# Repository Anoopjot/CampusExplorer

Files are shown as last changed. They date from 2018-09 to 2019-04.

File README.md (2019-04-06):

# Creating i2c Device(using ATtiny85, TMP36 and Arduino)

It involves various steps and the steps goes as follows:

Step 1. [Programming the Arduino(so that it can program ATtiny85)](https://github.com/HumberCampusExplorer/CampusExplorer#1-programming-the-arduino-to-program-the-attiny85)

Step 2. [Programming the ATtiny85](https://github.com/HumberCampusExplorer/CampusExplorer#2-programming-the-attiny85)

Step 3. [Wiring the circuit(Wiring Arduino + ATtiny85 + TMP36)](https://github.com/HumberCampusExplorer/CampusExplorer#3-wiring-the-circuit)

Step 4. [Programming the Arduino-To act as a master device](https://github.com/HumberCampusExplorer/CampusExplorer#4-programming-the-Arduino-to-act-as-a-master-device)

Step 5. [Power up the circuit](https://github.com/HumberCampusExplorer/CampusExplorer#5-power-up-the-circuit)

Step 6. [Testing](https://github.com/HumberCampusExplorer/CampusExplorer#6-testing)

Step Final. [Raspberry Pi](https://github.com/HumberCampusExplorer/CampusExplorer#creating-i2c-device(using-ATtiny85-TMP36-and-Arduino))

## Steps to program ATTiny85
[Follow this link](https://quadmeup.com/attiny85-light-sensor-i2c-slave-device/)

## 1 Programming the Arduino to program the ATtiny85
1. Stuff needed and used:-
- Arduino
- Breadboard
- ATtiny85 
- 220ohm 1/4 watt resistor
- LED
- hookup wires

2. Wire the circuit 

Connect the Arduino to the ATtiny as follows:

- Arduino +5V      --->  ATtiny Pin 8,

- Arduino Ground   --->  ATtiny Pin 4,

- Arduino Pin 10   --->  ATtiny Pin 1,

- Arduino Pin 11   --->  ATtiny Pin 5,

- Arduino Pin 12   --->  ATtiny Pin 6,

- Arduino Pin 13   --->  ATtiny Pin 7.

attiny85breadboardattiny85
arduino attiny85

3. Program the Arduino, so that it can program the microcontroller(ATtiny85), using "Arduino" software. To do that 3 steps need to be follow:

-> Select the "ArduinoISP" sketch from the "Examples" menu.

-> Upload the sketch to Arduino.

-> Check and make sure, from tools, the board selected is "Arduino/Genuino Uno",Port selected is same as the port on which the arduino is connected with the computer and select the programmer "AVR ISP", otherwise it will give the error related to serial.

-> And Finally, upload it.

-> Arduino is now configured as a serial programmer that can program other chips.

4. Add the Attiny85 core files by adding the following file/Folder url to arduino preferences:

[ATtiny_85](https://raw.githubusercontent.com/damellis/attiny/ide-1.6.x-boards-manager/package_damellis_attiny_index.json)

and going to board the manager and adding the board ATtiny85.

Unzip the .zip folder and save it in Arduino>libraries>

5. Program the ATtiny85

Select from the top menu:

Tools --> Board --> ATtiny85 (w/ Arduino as ISP)

Change the Programmer to "Arduino as ISP".

Then open the basic blink example and change the pin number from 13 to 4 and upload it.

6. Tested the circuit.

blinkled


and it shows that now arduino can program the ATtiny 85.

## 2 Programming the ATtiny85 

Now, we will be programming the ATtiny85 to act as slave,so that it can retrieve data(Analog value) from sensor(TMP36) and convert it to digital and send it to Raspberry pi, when requested.

First i am testing my circuit and program on Arduino(instead of Raspberry pi directly), to make troubleshooting easier.
For this purpose we need library, TinywireS libirary  from link
[TinyWireS_library](https://github.com/nadavmatalon/TinyWireS)

For that i uploaded this code on ATtiny85
```
/*
 * Set I2C Slave address. You can have multiple sensors with different addresses
 */
#define I2C_SLAVE_ADDRESS 0x30

/*
 * How often measurement should be executed
 * One tick is more less 0.5s, so 1 minute is 120 ticks
 * This executes measurements every 2 minutes, so 120s, 120000 ms
 */
#define MAX_TICK 50
#define STATUS_PIN_1 4
#define ADC_PIN A3
#define LPF_FACTOR 0.5

#include <TinyWireS.h>
#include <avr/sleep.h>
#include <avr/wdt.h>

#ifndef TWI_RX_BUFFER_SIZE
#define TWI_RX_BUFFER_SIZE ( 16 )
#endif

volatile uint8_t i2c_regs[] =
{
    0, //older 8
    0 //younger 8
};

volatile byte reg_position = 0;
const byte reg_size = sizeof(i2c_regs);
volatile unsigned int lightMeter;

/**
 * This function is executed when there is a request to read sensor
 * To get data, 2 reads of 8 bits are required
 * First requests send 8 older bits of 16bit unsigned int
 * Second request send 8 lower bytes
 * Measurement is executed when request for first batch of data is requested
 */
void requestEvent()
{  
  TinyWireS.write(i2c_regs[reg_position]);

  reg_position++;
  if (reg_position >= reg_size)
  {
      reg_position = 0;
      digitalWrite(STATUS_PIN_1, LOW);
  }
}

void setup() {
  /*
   * Setup I2C
   */
  TinyWireS.begin(I2C_SLAVE_ADDRESS);
  TinyWireS.onRequest(requestEvent);

  /*
   * Set pins
   */
  pinMode(STATUS_PIN_1, OUTPUT);
  pinMode(ADC_PIN, INPUT);
}

unsigned int tick = 0;
unsigned long lastReadout = 0;

int smooth( int data, float filterVal, float smoothedVal){
return(data);
}

void loop() {

  unsigned long currentMillis = millis();
  /*
   * On tick value 0, do measurements
   */
  if (abs(currentMillis - lastReadout) > MAX_TICK) {
   int raw_value = analogRead(ADC_PIN);
   
    lightMeter = smooth(raw_value, LPF_FACTOR, lightMeter);
    
    i2c_regs[0] = (lightMeter >> 8) & 0xFF;     // shifting the 8 bits
    i2c_regs[1] = lightMeter & 0xFF;            
    
    digitalWrite(STATUS_PIN_1, HIGH);
    lastReadout = currentMillis;
  }
}
```
* check for Board choose "ATtiny85" and programmer as "Arduino as ISP".
And upload the code.

## 3 Wiring the circuit
(Wiring Arduino + ATtiny85 + TMP36)

ATtiny 85 & TMP36
- Pin2 (ATtiny85) -> centre pin(tmp36)
- Pin 1(TMP36) -> 5v
- Pin3 (TMP36) -> Ground

To check pins of TMP36

tmp36pinout

Arduino & ATtiny85
- Pin4(ATtiny85) - Ground
- Pin8(ATtiny85) - Vcc(5v)
- Pin5(ATtiny85) - SDA (Arduino)
- Pin7(ATtiny85) -SCL (Arduino)
We need to insert pull-up resistor (nearly 4.7k ohm ) between pin 5 (ATtiny85) and Vcc && between pin 7 (ATtiny85) and Vcc.

Then attach the auduino with USB cable type A/B with computer to power up Arduino.

pcbwithtmp36arduinobbwithtmp36arduino
arduinoattiny85tmp36

# 4 Programming the Arduino to act as a master device

For this i just uploaded a sketch to arduino.

For that i changed the options from ARDUINO software=> 
- Tools-> Board:"Arduino/Genuino uno" and 
- Tools-> Programmer:"AVR ISP"

AND then uploaded the "sketch"

```
#include <Wire.h>

int i = 0;
unsigned int readout = 0;
byte FirstByte =0;
byte SecondByte =0;
 
void setup() {
  Serial.begin(9600);  // start serial for output
  Serial.println("starting");
  Wire.begin();        // join i2c bus (address optional for master)
}

void loop() {
  Wire.requestFrom(0x30, 1);    // request 1 bytes from slave device #0x13
 while(Wire.available()){
 FirstByte = Wire.read();
}

Wire.requestFrom(0x30, 1);    // request 1 bytes from slave device #0x13
 while(Wire.available()){
 SecondByte = Wire.read();
}
 readout = FirstByte << 8|SecondByte;       // putting them together
 Serial.println(readout);
 delay(13);
}
```

# 5 Power up the circuit
Now attach (USB cable type A/B) to computer, to power it and complete the circuit and test it. 

# 6 Testing 
Then, after completing all the steps, checked the output at Serial Monitor. 
and the output should be similar to this. You can uncheck the Autoscroll option to have a clear look over readings.

Output
Output

After following all the step, it will start measuring the temperature from TMP36 through Arduino.The readings are the digital value.

# Creating i2c Device(using ATtiny85, TMP36 and Raspberry pi)
Now, we will try to get reading on Raspberry pi. It should not be a issue because the ATtiny85 is already programmed,now we just need to put the program on Raspberry pi.

Connect the Raspberry pi with the ATtiny85 and the connections are as follow:

(Wiring Raspberry pi + ATtiny85 + TMP36)

ATtiny 85 & TMP36
- Pin2 (ATtiny85) -> centre pin(tmp36)
- Pin 1(TMP36) -> PIN2 (Raspberry pi)
- Pin3 (TMP36) -> Ground

Raspberry pi & ATtiny85
- Pin4(ATtiny85) - Pin 9(Ground)
- Pin8(ATtiny85) - Pin 1(Vcc(3.3v))
- Pin5(ATtiny85) - Pin 3(SDA)
- Pin7(ATtiny85) - Pin 5(SCL)
We need to insert pull-up resistor (nearly 4.7k ohm ) between pin 5 (ATtiny85) and Vcc && between pin 7 (ATtiny85) and Vcc.

TMPRpiFritz

Another thing which need to be kept in mind while making connections, is TMP36 will give exact reading only if it is connected to 5V (although, in [Datasheet](https://www.analog.com/media/en/technical-documentation/data-sheets/TMP35_36_37.pdf) it says it can work on power supply between 3v & 5v, but when i tried it was giving wrong readings). So I connected the TMP36 with 5v and ATtiny85 with 3.3 v.

Then connect the Raspberry pi with screen using HDMI to VGA cable and VGA adapter and give it a power supply.
It Should start, Raspberry should have operating system already installed, i bought like that only. It already had the NOOBS installed then go to terminal.

WiringPi is PRE-INSTALLED with standard Raspbian systems. Check for wiringPi library, by issuing the command:
-gpio -v
-gpio readall

I have uploaded this code on Raspberry pi:
```
#include <stdio.h>
#include <stdlib.h>
#include <math.h>
#include <wiringPi.h>
#include <wiringPiI2C.h>

int i = 0;
unsigned int readout = 0;
unsigned int Voltage = 0;
unsigned int Temperature = 0;
int FirstByte =0;
int SecondByte =0;

int main (void) {
        int fd;
        wiringPiSetup();
        fd = wiringPiI2CSetup(0x30);
        while(1)
        {
                FirstByte = wiringPiI2CRead(fd);
                SecondByte = wiringPiI2CRead(fd);
 
                readout = FirstByte << 8|SecondByte;
                Voltage = ((readout*3300)/1024);
                Temperature = ((Voltage-500)/10);
                printf("Temperature: %d°C \n",Temperature);
                delay(13);
        }

        return(0);

}

```

In this code, i converted the digital reading into the voltage using formula{Voltage = ((digital value*3300)/1024)}

and then the voltage into the temperature degree celcius, using formula{Temperature=((voltage-500)/10)}

then compile the code using command:
- gcc -o tmp36 tmp36.c -lwiringPi

and run it using command:
- sudo ./tmp36
 
 It should work, and should give reading as follow:
 RpiReading2Final
 
 And That it!

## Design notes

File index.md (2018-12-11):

# Humber Campus Navigator
For students it is hard to navigate within the campus. We are designing an application which helps students to navigate within the campus from any point to any point in short time and less distance and it will show temperature and pressure at that point.This project will consist various sensors,from them, temperature sensor(TMP36), pressure sensor(STM32) and 9-axis IMU(LSM9DS0) are the major ones.

# Week 15 
Updated Readme.md and index.md to put instructions in it and explained the processes and steps I followed to get there.

# Week 14 
Presented Idea, progress, and result to class and Professor, and discussed with Kelly and Vlad and tried to get it work gave last try on Friday.But it it still showing the same output.

# Week 13
[Presentation]https://github.com/HumberCampusExplorer/CampusExplorer/blob/master/Presentation.pptx

# Week 12
Tried my best to get it work, but i am getting some output but not the desired.

# Week 11
To reduce the confusion from week 10 I will write the build instructions for the steps I took in week 9 in [readme.md](https://github.com/HumberCampusExplorer/CampusExplorer/blob/master/README.md)

# Week 10 (Nov 6)
Although, this week is PCB soldering milestone, but i am still trying to figure out my coding part for my raspberry pi, so that it can request data from ATtiny85 and display it. I am little bit behind according to my Schedule, but before i was kind of confused(how i am going to do my sensor project), but now i figured out the steps i need to follow, in order to accomplish my hardware part, After completing my raspberry pi coding part, i will try my best to pace up for my project, I don't have to do soldering part, i just have to assemble my sensor, ATtiny85 with raspberry pi, then i should be good. 

# Week 9 (Oct 30)
This Week was PCB designed milestone, and i programmed my ATtiny85, which is sending data to raspberry pi when requested. I uploaded the program to ATtiny85 using Arduino Uno(hardware) and a software "Arduino". 

# Week 8 (Oct 23)
This week was breadboard assembly milestone, but in my case, before assembling my breadboard, i need to program my ATtiny85 microcontroller - For that-> First i programmed arduino, so that it can program ATtiny85, then i have to program Attiny85, so that it can convert my voltage reading into analog reading and then to digital. And then, Finally, i need to program my raspberry pi, so that it can request data from ATtiny85 and display it.So, for this week i programmed my arduino and tested it using a test program(blink Led) anfd it was successful, and the led was blinking.

blinkled

# Week 7 (Oct 16)
Pseudo Code Assignment & Acquisitions.



uml diagram

# Week 6 (Oct 9)
Reading Week.

# Week5 (Oct 2)
Parts Ordered.
These are the invoices for the products which i ordered. I ordered them with my group member Bettin Jacob, The products include: Raspberry pi b+, 32GB SD-Card, TMP36-Temperature Sensor,ATtiny85 8-bit 20 MHz AVR Microcontroller, Jumper Wires & 8 Pin DIP Socket.

amazon
robotshop 

# Week 4 (Sept 25)
Budget.
https://github.com/HumberCampusExplorer/CampusExplorer/blob/master/DhalluBudget.xlsx

budget

# Week 3 (sept 18)
Schedule.
https://github.com/HumberCampusExplorer/CampusExplorer/blob/master/Schedule.docx

schedule

# Week 2 (Sept 11)
Proposal.
https://github.com/HumberCampusExplorer/CampusExplorer/blob/master/Proposal.xlsx

proposal

# Week 1 (Sept 4)
Main agendas of this week were Introduction, Crib pi, chosing sensor and project.
In week1, course outline and critical path of the course was introduced, and the professor told us what we will be doing in the coming weeks, then, there was a description of the hardware we will be using in the course and in the project.

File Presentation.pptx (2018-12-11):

## Creating i2c device

Using ATtiny85 and TMP 36 with Raspberry pi.

## ATtiny85

- It is a 8-bit microcontroller , it has many properties, but in my case it is acting as a ADC converter, which act as a slave device. It sends temperature reading when requested by raspberry pi.

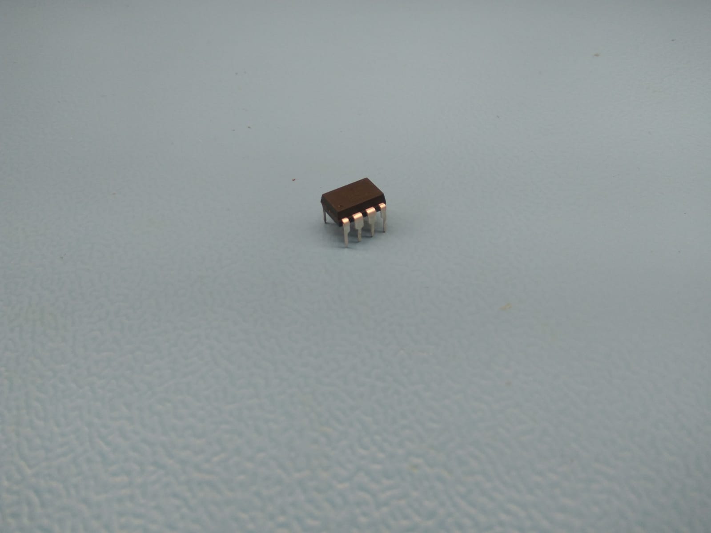
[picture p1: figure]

## TMP36

- It is a analog sensor, which records temperature, and sends reading to ATtiny85, when requested.

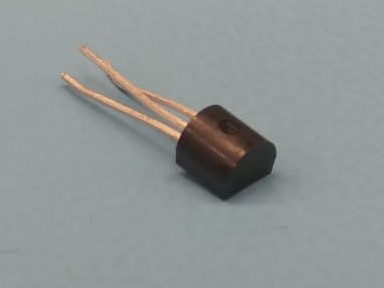
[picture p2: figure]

## Arduino + ATtiny85 + TMP36

- My project includes creating a i2c device with ATtiny85. Basically, in project, Raspberry pi acts as a master device and requests data from ATtiny85, on the other hand, ATtiny85 acts as a Slave device, which records a analog value from TMP36(Temperature Sensor) and converts it into digital and sends it to Raspberry pi over i2c, when requested.

## Budget

- Raspberry pi $80
- TMP36(Temperature Sensor) $2.20
- ATtiny85(8-Bit microcontroller) $4.20
- Jumper Wires $4.60
- 8 pin DIP Socket $1.00
- Shipping $20
- Total $112

## Schedule

- I have a long delay in my project, after breadboarding , I cannot do PCB design and soldering unless my sensor is showing reading because I have to take my ATtiny85 again and again to program it, to test it.

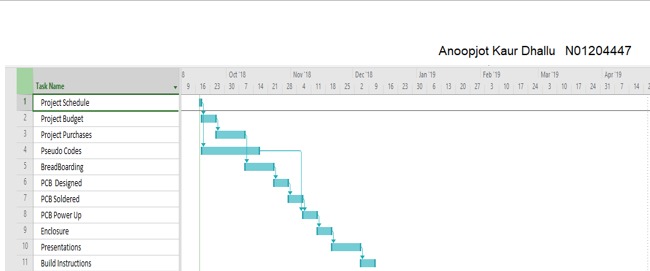
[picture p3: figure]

## Tests

During my project I ran into various tests
-> With Arduino, it showed correct output.
But Challenge was to do it with Raspberry pi, in case of raspberry pi, it is
Showing readings but in analog, so the last issue left is with the ADC converter function.

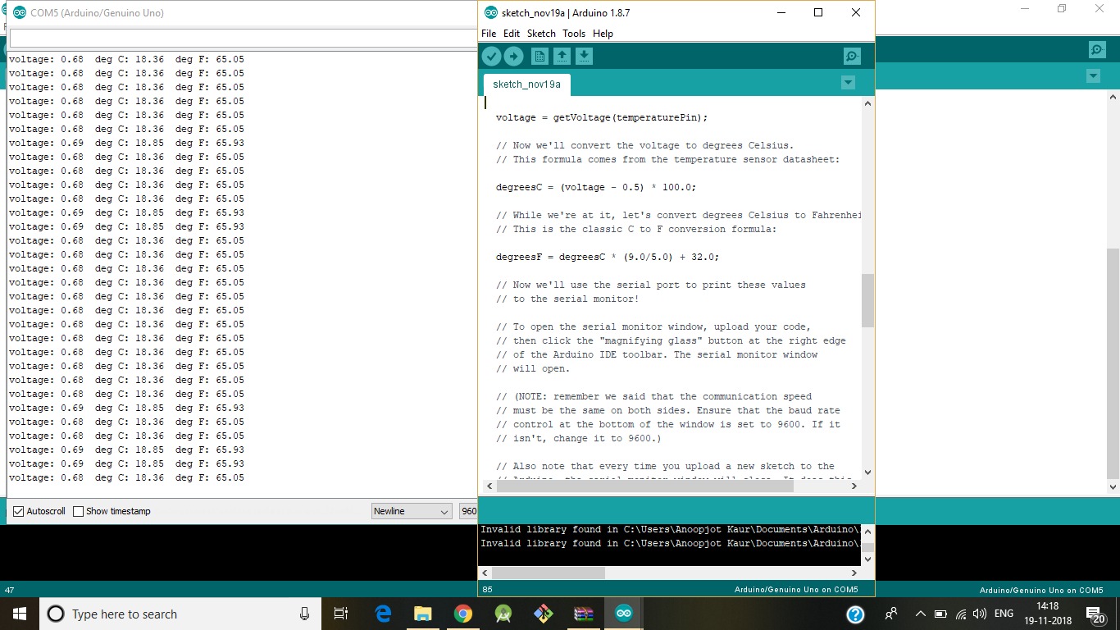
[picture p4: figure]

## Current output

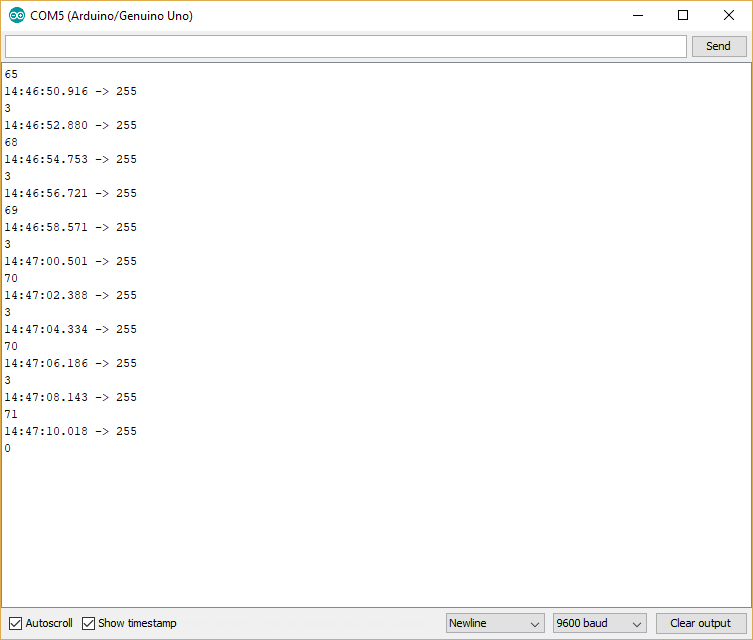
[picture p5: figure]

## Course Knowledge utilized from previous courses.

- Sem1- Tech101(Electric Circuits), Tech103(Digital Fundamentals)
- Sem2- Tech153(Technical C),Tech150(Electronic Devices and Circuits)
- Sem3- CENG215(Digital & Interface Systems), CENG216(Software Eng.)
- Sem4- CENG250(PC OS Internals), CENG252(Embedded Systems)

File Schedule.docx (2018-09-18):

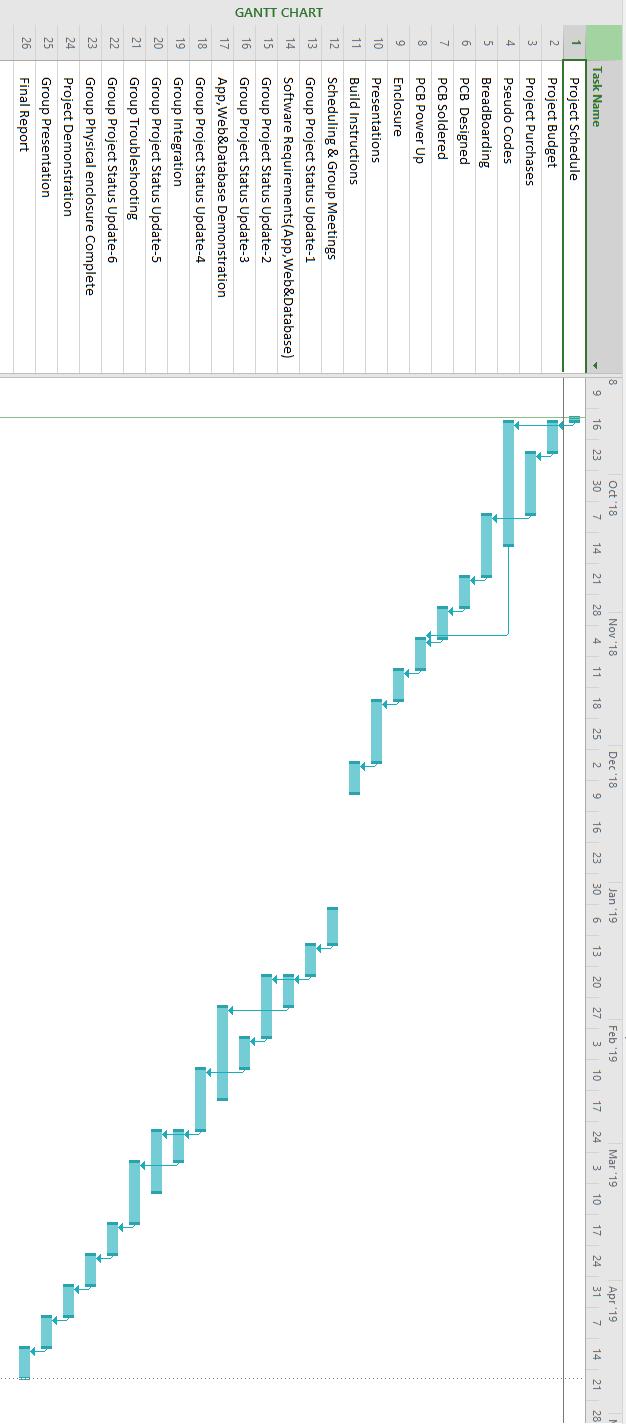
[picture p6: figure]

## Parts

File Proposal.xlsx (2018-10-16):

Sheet: DataEntry
Submission Date | 2018-09-11
Project Name | Humber Campus Navigator
Student Name | Anoopjot Kaur Dhallu
Project repository | https://github.com/HumberCampusExplorer/CampusExplorer.git
SensorEffector choice | TMP36-Temperature Sensor 0x30
The database will store | Map of the Humber Campus, Phone numbers
The mobile device functionality will include | Navigation within the campus
I will be collaborating with the following company/department | Humber College Facilities and FYI
My group in the winter semester will include | Bettin Jacob & Ishan khuttan
50 word problem statement | For students it is really hard to navigate within the campus. We are designing an application which helps students to navigate within the campus from any point to any point in short time and less distance.
100 words of background | When we were new to college, we used to roam inside the campus to find anything within the campus. It was really tiresome. Even in this semester it was difficult for me in finding the location of NB part of the college.
Current product APA citation | Jana S., & Chattopadhyay M.(2015). An event-driven university campus navigation system on android platform.Retrieved from https://ieeexplore.ieee.org/document/7083850/
Existing research IEEE paper APA citation | González-Guerrero, M., Jiménez, J.J., Hernando, C., Álvarez, M. and Guerrero,H.( 2013). Dosimeter for The Two Towers in SEOSAT-INGENIO Based on the TMP36 Temperature Sensor. Retrieved from https://ieeexplore.ieee.org/document/6516099/
Brief description of planned purchases | 1. Raspberry pi kit with touch screen 2. Some sensors
Solution description | We have two solutions in mind. 1. Real time Navigation - with location sensors installed in various locations of campus, through a mobile app, we can give a real time navigation guidance for users. But this will be expensive. 2. Offline Navigation - With QR code sticked to all the class room doors of the campus, user can just scan the QR code where he stands and select a location anywhere on campus and the app will give the easiest path to that location.

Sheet: DataBase
Submission Date | Project Name | Student Name | Project repository | SensorEffector choice | The database will store | The mobile device functionality will include | I will be collaborating with the following company/department | My group in the winter semester will include | 50 word problem statement | 100 words of background | Current product APA citation | Existing research IEEE paper APA citation | Brief description of planned purchases | Solution description
43354 | Humber Campus Navigator | Anoopjot Kaur Dhallu | https://github.com/HumberCampusExplorer/CampusExplorer.git | TMP36-Temperature Sensor 0x30 | Map of the Humber Campus, Phone numbers | Navigation within the campus | Humber College Facilities and FYI | Bettin Jacob & Ishan khuttan | For students it is really hard to navigate within the campus. We are designing an application which helps students to navigate within the campus from any point to any point in short time and less distance. | When we were new to college, we used to roam inside the campus to find anything within the campus. It was really tiresome. Even in this semester it was difficult for me in finding the location of NB part of the college. | Jana S., & Chattopadhyay M.(2015). An event-driven university campus navigation system on android platform.Retrieved from https://ieeexplore.ieee.org/document/7083850/ | González-Guerrero, M., Jiménez, J.J., Hernando, C., Álvarez, M. and Guerrero,H.( 2013). Dosimeter for The Two Towers in SEOSAT-INGENIO Based on the TMP36 Temperature Sensor. Retrieved from https://ieeexplore.ieee.org/document/6516099/ | 1. Raspberry pi kit with touch screen 2. Some sensors | We have two solutions in mind. 1. Real time Navigation - with location sensors installed in various locations of campus, through a mobile app, we can give a real time navigation guidance for users. But this will be expensive. 2. Offline Navigation - With QR code sticked to all the class room doors of the campus, user can just scan the QR code where he stands and select a location anywhere on campus and the app will give the easiest path to that location.

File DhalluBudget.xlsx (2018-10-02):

 |  | Anoopjot Kaur Dhallu
Sr No | Quantity | Item | Supplier | Description | Link | Price(Tax Inc.)
1 | 1 | Raspberry Pi 3 B+ Kit(2.5A Power Supply included) | Amazon | It is a microcontroller. It will be used in Capstone Group Project. | https://www.amazon.ca/CanaKit-Raspberry-Power-SupplyListed/dp/B07BD3WHCK | $80.00
2 | 1 | Sandisk Ultra 32GB SD card | Amazon | Operating System for raspberry pi will be stored on this micro SD-Card | https://www.amazon.ca/Sandisk-Ultra-Class-Memory-SDSDUNC032GGN6IN/dp/B0143RT8OY?s=electronics | $18.65
3 | 1 | Temperature Sensor-TMP36 | RobotShop | This is my main focus for this Semester. It is used to measure the temperature. | https://www.robotshop.com/ca/en/temperature-sensor-tmp36.html | $2.20
4 | 1 | ATtiny85 8-bit 20MHz AVR Microcontroller | RobotShop | It is a microcontroller developed by Atmel, used for small projects. I will be using it with temperature sensor. | https://www.robotshop.com/ca/en/attiny85-8-bit-20mhz-avr-microcontroller.html | $4.20
5 | 120 | Jumper wires | Amazon | Jumper Wires will be used for wiring the raspberry pi with the sensors in the project.I will be sharing them with group members. | https://www.amazon.ca/120pcs-Multicolored-Breadboard-Arduino-Raspberry/dp/B072L1XMJR | $12.40
6 | 1 | 8 pin DIP Socket | Amazon | It will be used as a placeholder for ATtiny85 microcontroller and it will allow safe and easy insertion and removal of ATtiny85 microcontroller. | https://www.amazon.ca/Robojax-Socket-Solder-Dip-8-Round/dp/B07BKB11S7 | $1.00
7 | 1 | Parts Kit | Humber College(Book Store) | It includes essential tools and equipments, needed for hardware projects in the course.It includes wires for conections, Screw Driver, BreadBoard and sensors. |  | $120.00
8 | 1 | PCB | Humber College (Prototype Lab) | PCB is done to allow signals and power to be routed between physical devices.Basically it makes the finishing product more compact. |  | FREE
9 | 1 | Shipping | RobotShop | UPS Standard Shipping for RobotShop.com |  | $20.00
 |  | TOTAL |  |  |  | $258.45

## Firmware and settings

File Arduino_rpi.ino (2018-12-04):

#include <Wire.h>

int i = 0;
unsigned int readout = 0;

void setup() {
  Wire.begin();        // join i2c bus (address optional for master)
  Serial.begin(9600);  // start serial for output
  Serial.println("starting");
}

void loop() {
  Wire.requestFrom(0x30, 2);    // request 2 bytes from slave device #0x30

  int i = 0;
  unsigned int readout = 0;
  while (Wire.available()) { // slave may send less than requested
    byte byteRecieved = Wire.read(); // receive a byte as character

    if (i == 0) {
      readout = byteRecieved;
    } else {
      readout = readout << 8;
      readout = readout + byteRecieved;
    }

    i++;
  }
 delay(100);

}

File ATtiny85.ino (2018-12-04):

/*
 * Set I2C Slave address. You can have multiple sensors with different addresses
 */
#define I2C_SLAVE_ADDRESS 0x30

/*
 * How often measurement should be executed
 * One tick is more less 0.5s, so 1 minute is 120 ticks
 * This executes measurements every 2 minutes, so 120s, 120000 ms
 */
#define MAX_TICK 20

#define STATUS_PIN_1 1
#define ADC_PIN A3

#define LPF_FACTOR 0.5

#include <TinyWireS.h>
#include <avr/sleep.h>
#include <avr/wdt.h>

#ifndef TWI_RX_BUFFER_SIZE
#define TWI_RX_BUFFER_SIZE ( 16 )
#endif

volatile uint8_t i2c_regs[] =
{
    0, //older 8
    0 //younger 8
};

volatile byte reg_position; // = 0;
const byte reg_size = sizeof(i2c_regs);

/*
 * 0=16ms
 * 1=32ms
 * 2=64ms
 * 3=128ms
 * 4=250ms
 * 5=500ms
 * 6=1 sec,
 * 7=2 sec,
 * 8=4 sec,
 * 9= 8sec
 */
//for resetting the microcontroller automatically and to avoid malfunction of the chip

void setup_watchdog(int ii) {
  byte bb;
  int ww;
  if (ii > 9 ) ii=9;
  bb=ii & 7;
  if (ii > 7) bb|= (1<<5);
  bb|= (1<<WDCE);
  ww=bb;

  MCUSR &= ~(1<<WDRF);
  
  // start timed sequence
  
  WDTCR |= (1<<WDCE) | (1<<WDE);
  // set new watchdog timeout value
  WDTCR = bb;
  WDTCR |= _BV(WDIE);
}

/*
 * Watchdog Interrupt Service is executed when  watchdog timed out
 */
ISR(WDT_vect) {
  digitalWrite(STATUS_PIN_1, LOW);
}

volatile unsigned int lightMeter;

/**
 * This function is executed when there is a request to read sensor
 * To get data, 2 reads of 8 bits are required
 * First requests send 8 older bits of 16bit unsigned int
 * Second request send 8 lower bytes
 * Measurement is executed when request for first batch of data is requested
 */
void requestEvent()
{  
  TinyWireS.send(i2c_regs[reg_position]);

  reg_position++;
  if (reg_position >= reg_size)
  {
      reg_position = 0;
  }
}

void setup() {
  /*
   * Setup I2C
   */
  TinyWireS.begin(I2C_SLAVE_ADDRESS);
  TinyWireS.onRequest(requestEvent);

  /*
   * Set pins
   */
  pinMode(STATUS_PIN_1, OUTPUT);
  pinMode(ADC_PIN, INPUT);

  /*
   * Start watchdog timer
   */
  setup_watchdog(6);
}

unsigned int tick;    //= 0;
unsigned long lastReadout; //= 0;
//to take the average of the analog values
int smooth(int data, float filterVal, float smoothedVal){

  if (filterVal > 1){      // check to make sure params are within range
    filterVal = .99;
  }
  else if (filterVal <= 0){
    filterVal = 0;
  }

  smoothedVal = (data * (1 - filterVal)) + (smoothedVal  *  filterVal);

  return (int)smoothedVal;
}

void loop() {

  set_sleep_mode(SLEEP_MODE_PWR_DOWN);
  sleep_enable();
  sleep_mode();
  sleep_disable(); 

  unsigned long currentMillis = millis();
  /*
   * On tick value 0, do measurements
   */
  if (abs(currentMillis - lastReadout) > MAX_TICK) {
    int raw_value = analogRead(ADC_PIN);

    lightMeter = smooth(raw_value, LPF_FACTOR, lightMeter);
    
    i2c_regs[0] = lightMeter >> 8;
    i2c_regs[1] = lightMeter & 0xFF;
    
    digitalWrite(STATUS_PIN_1, HIGH);
    lastReadout = currentMillis;
  }
}
